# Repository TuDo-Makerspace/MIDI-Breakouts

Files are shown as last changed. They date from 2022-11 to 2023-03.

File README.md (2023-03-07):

# Just another pair of MIDI breakout boards <!-- omit in toc -->

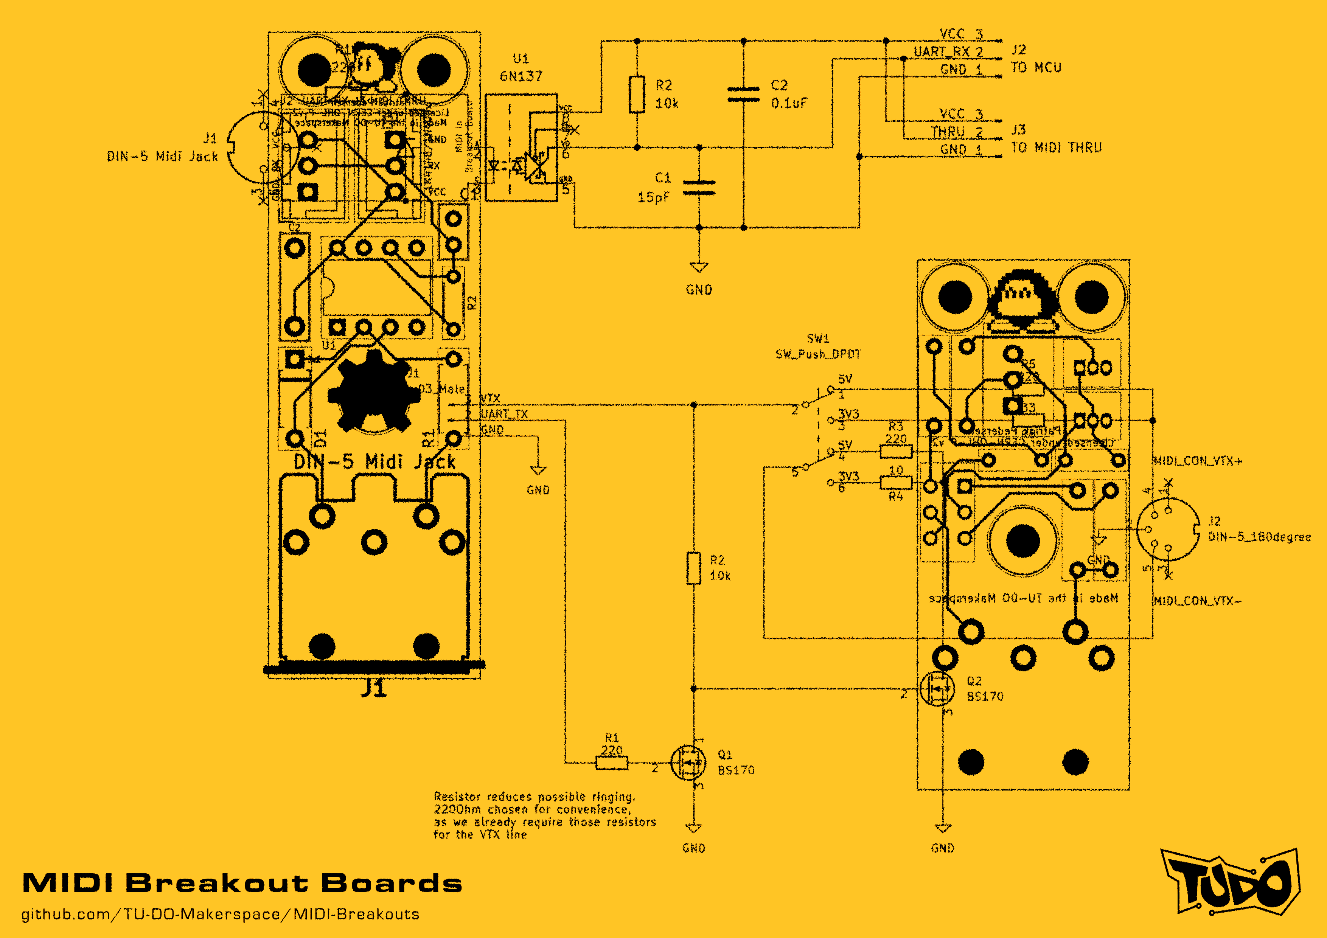
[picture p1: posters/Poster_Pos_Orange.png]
poster


## Table of Contents <!-- omit in toc -->

- [Overview & Background](#overview--background)
- [Noteworthy Features](#noteworthy-features)
- [Schematics](#schematics)
	- [MIDI IN](#midi-in)
	- [MIDI OUT](#midi-out)
- [Ordering](#ordering)
- [Parts & Assembly](#parts--assembly)
- [Pictures](#pictures)
- [License](#license)

## Overview & Background

This repository contains the KiCad files for a pair of MIDI breakout boards. There isn't anything particularly special about them, besides perhaps the fact that the MIDI OUT has a switch to select between 3.3V and 5V operation, as well as two BS170 MOSFETs to sink the current, rather than using buffer chips. Oh, and we use JST-XH connectors, because I hate those loose "DuPont" headers that allow you to plug things in the wrong way around! >:(

Further, one may also question the odd choice of some components, such as the 100nF film capacitor for voltage decoupling, instead of a 100nF ceramic capacitor.
This really leads us to why these boards have even been made in first place. They were really just intended as test boards to try out some [template MIDI schematics](https://github.com/TU-DO-Makerspace/KiCAD-MIDI-Templates) I designed for future projects that require MIDI support. The components were chosen according to the stuff we had lying around in our lab, hence the quirky choice of components and varying resistor footprints.

I'm still dumping this on GitHub, as we still have a few of these boards lying around and the repo serves as good documentation, but perhaps someone out there might also find them useful. After all, if you don't feel like using pricey film caps, you can always just pop in a ceramic one instead! The footprint is not that different!

## Noteworthy Features

MIDI IN:

 - Utilizes the faster 6N137 Optocoupler opposed to the more common 6N138
 - Uses a 15pF decoupling capacitor on the optocoupler's output for better noise immunity
 - Provides two parallel JST-XH connectors:
   - One to connect to the receiving device (eg. a MCU)
   - One to directly connect to a MIDI OUT board which gives you a MIDI THRU output

MIDI OUT:

 - Utilizes two BS170 MOSFETs to sink the current, rather than using buffer chips
 - Has a switch to select between 3.3V and 5V operation
 - Uses a JST XH connector to connect to the sending device (eg. a MCU, or a MIDI IN board for MIDI THRU)

Both boards are compliant with the MIDI Specification

## Schematics

### MIDI IN
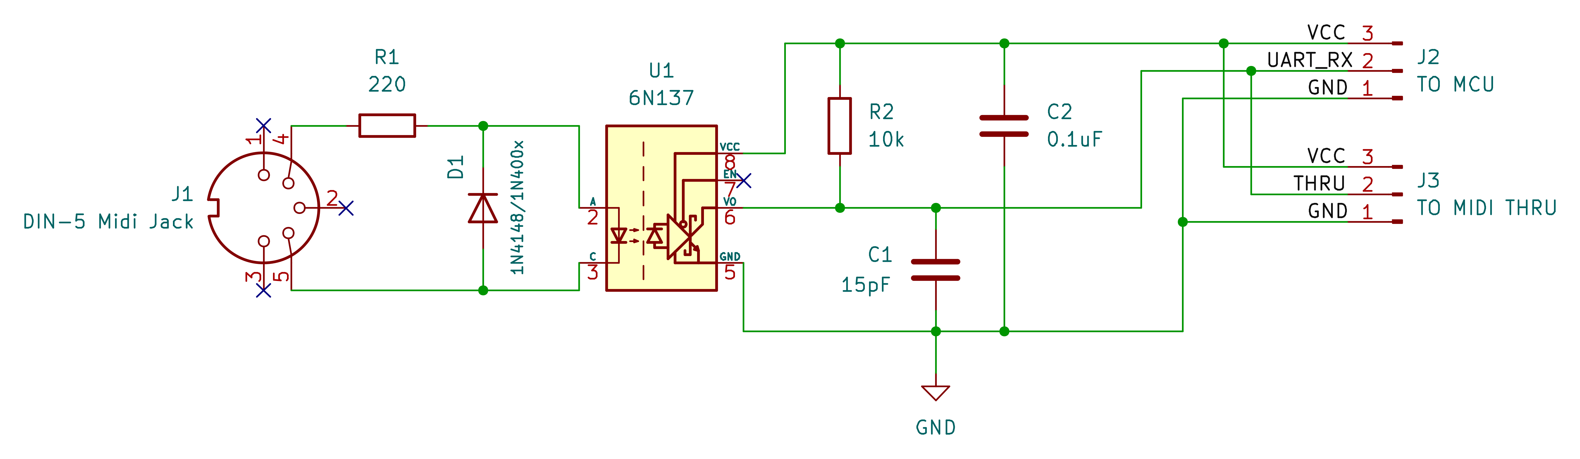
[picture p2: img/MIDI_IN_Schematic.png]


### MIDI OUT
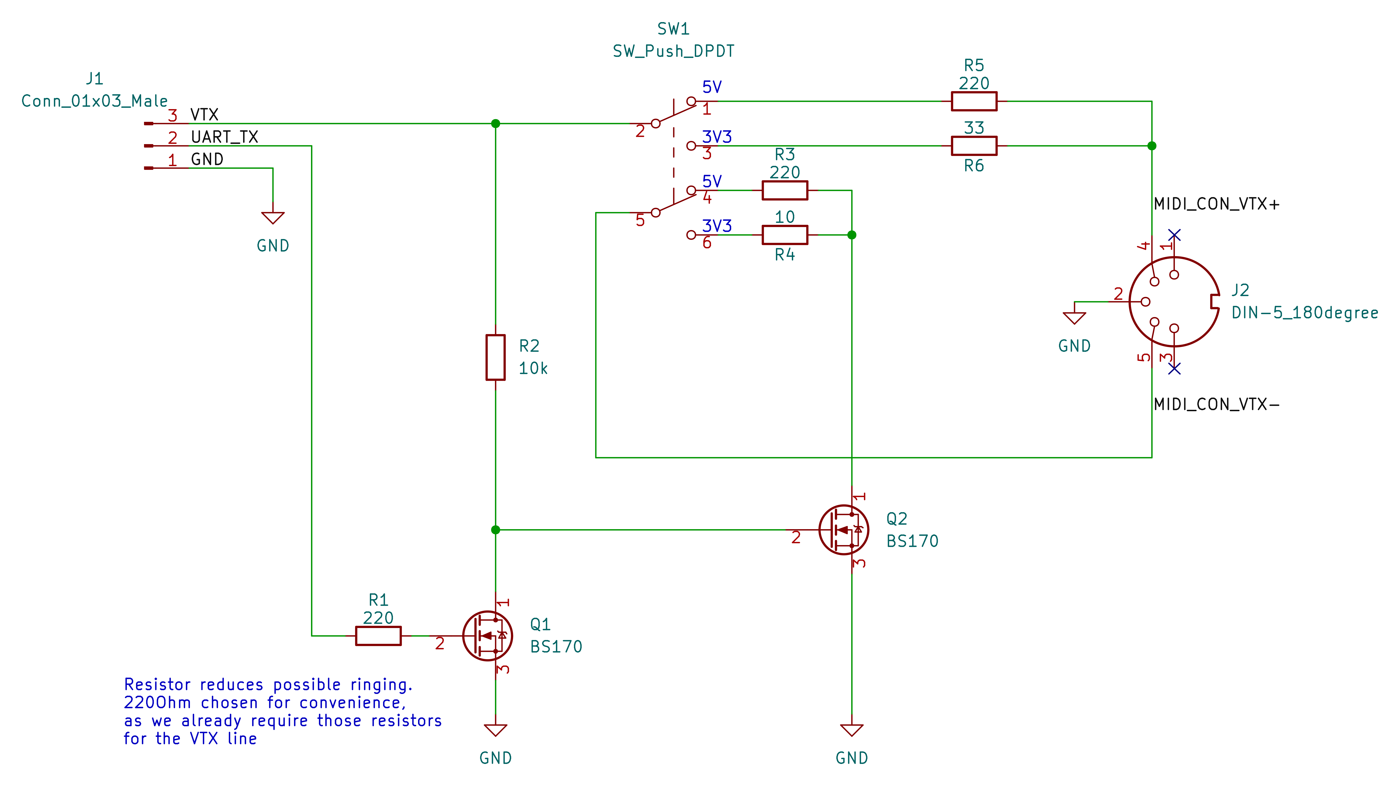
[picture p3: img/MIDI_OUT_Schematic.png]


## Ordering

The directories for the individual boards contain a "Gerbers" directory, which contains the gerber files for the respective board. You can use these to order the boards from your desired PCB manufacturer.

## Parts & Assembly

An interactive BOM for both boards can be found [here](https://tu-do-makerspace.github.io/MIDI-Breakouts/)

The interactive bom contains a PCB view that allows you to see which components go where, and what value they have.
This is particularly useful to have open while assembling the boards.

## Pictures

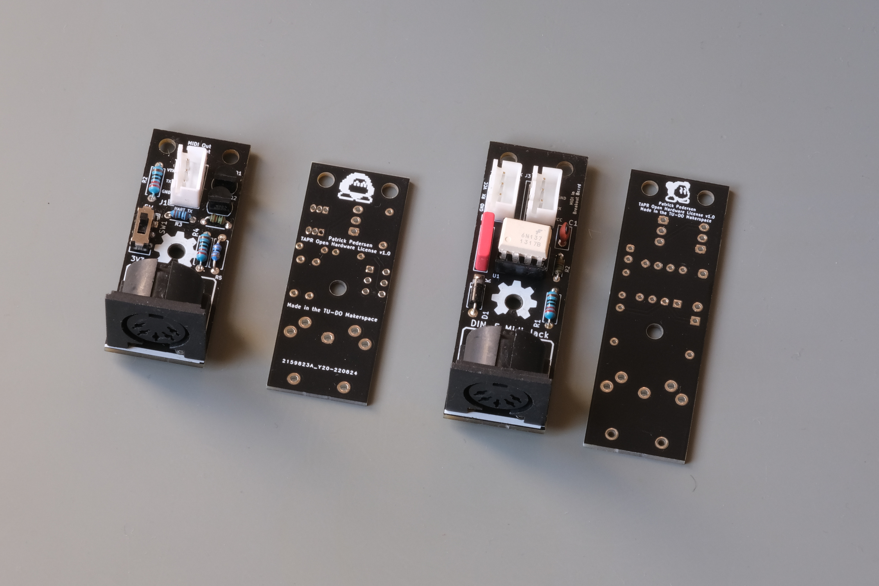
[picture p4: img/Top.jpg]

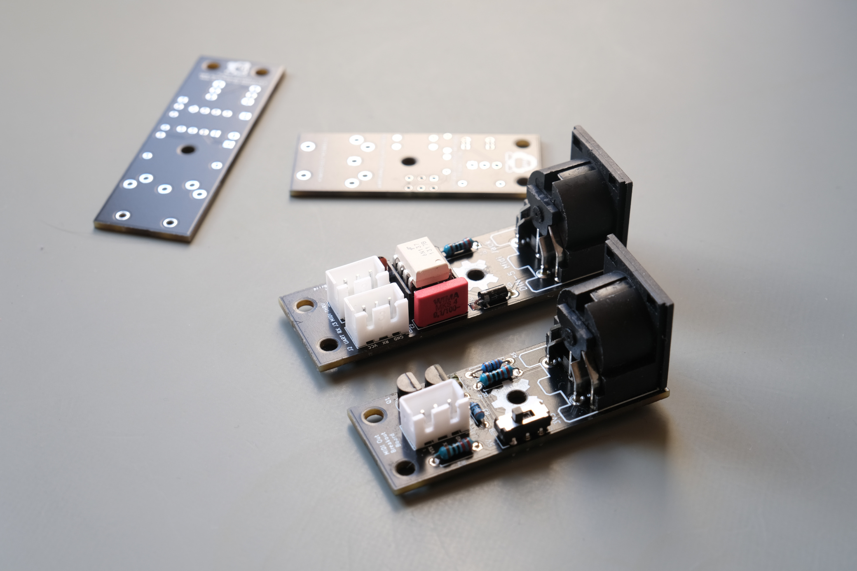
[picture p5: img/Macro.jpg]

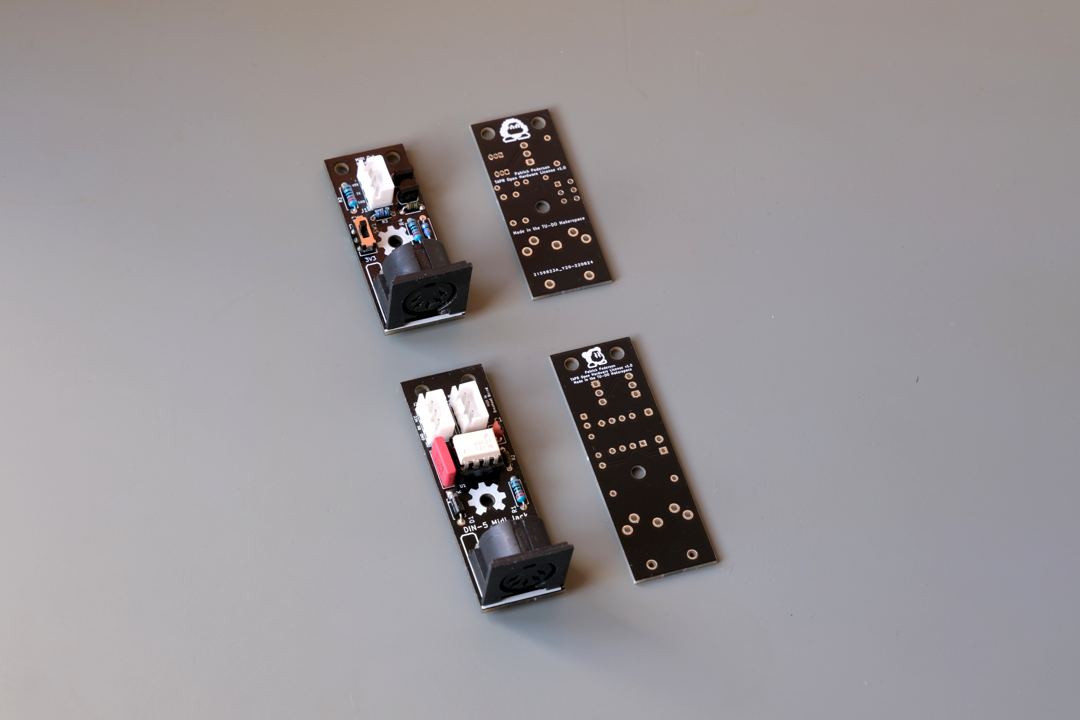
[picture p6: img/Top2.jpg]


## License

The following project is licensed under the [CERN-OHL-P v2 license](https://ohwr.org/cern_ohl_p_v2.pdf)

The boards on the pictures claim `TAPR Open Hardware License v1.0`, however, the KiCAD project has been updated to use the CERN-OHL-P v2 license.

Crediting is always appreciated, even for something as trivial as a pair of breakout boards!

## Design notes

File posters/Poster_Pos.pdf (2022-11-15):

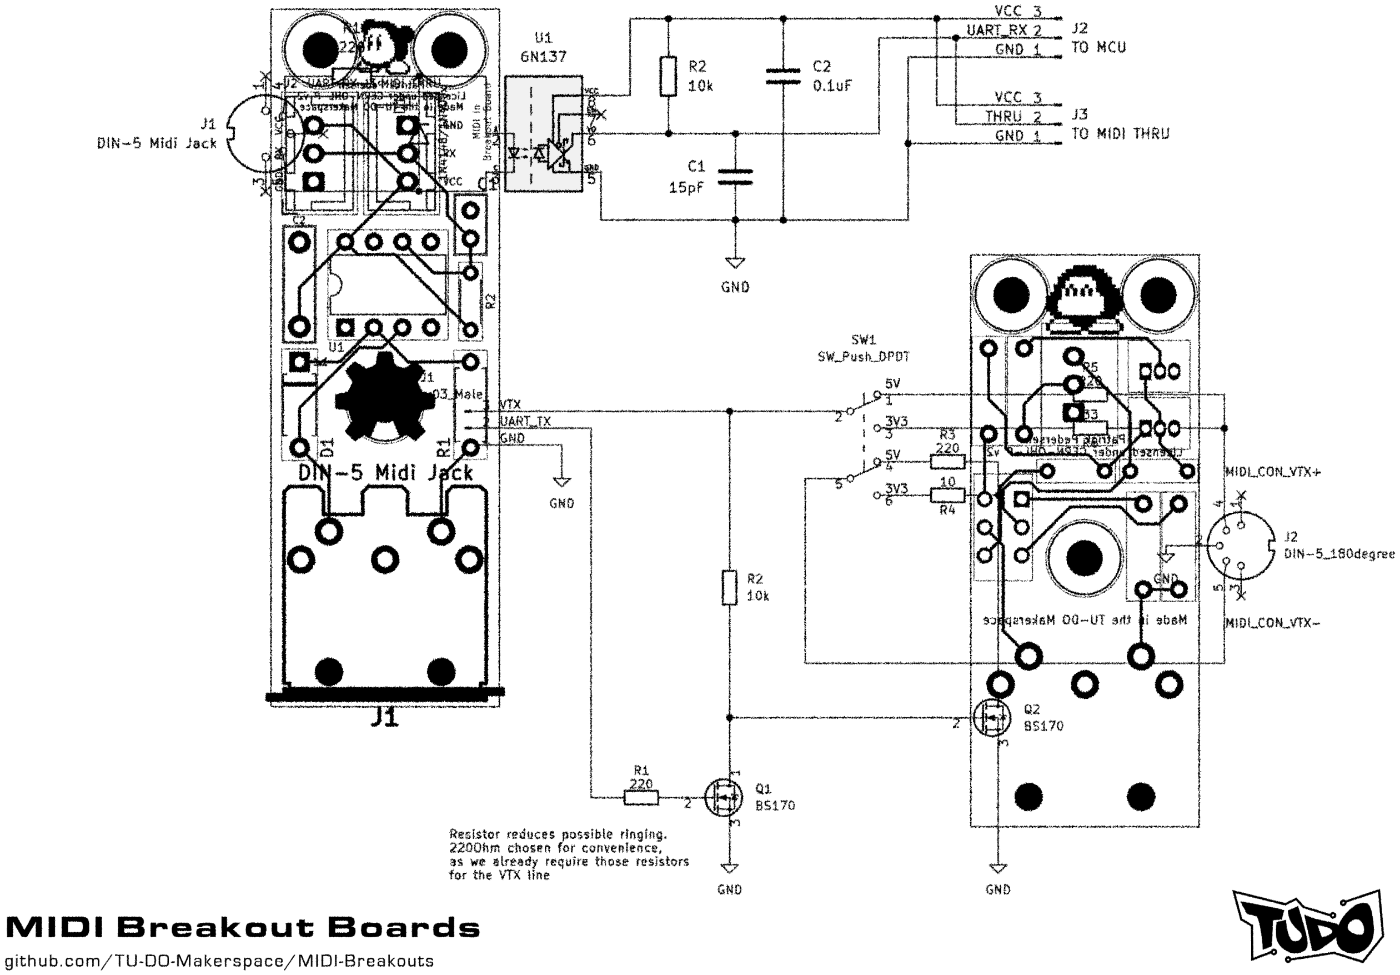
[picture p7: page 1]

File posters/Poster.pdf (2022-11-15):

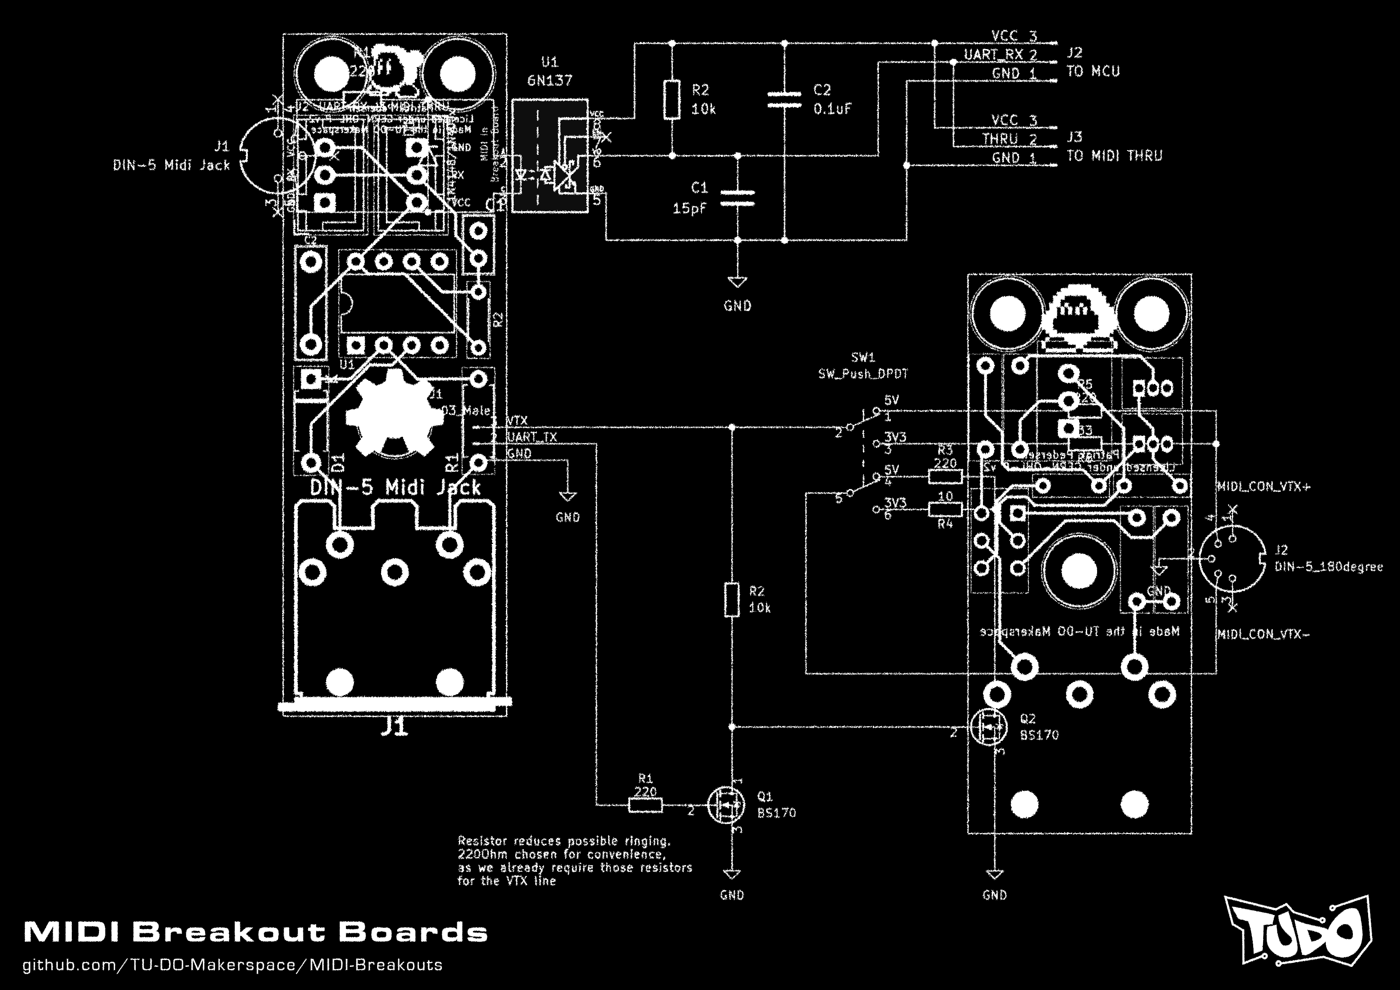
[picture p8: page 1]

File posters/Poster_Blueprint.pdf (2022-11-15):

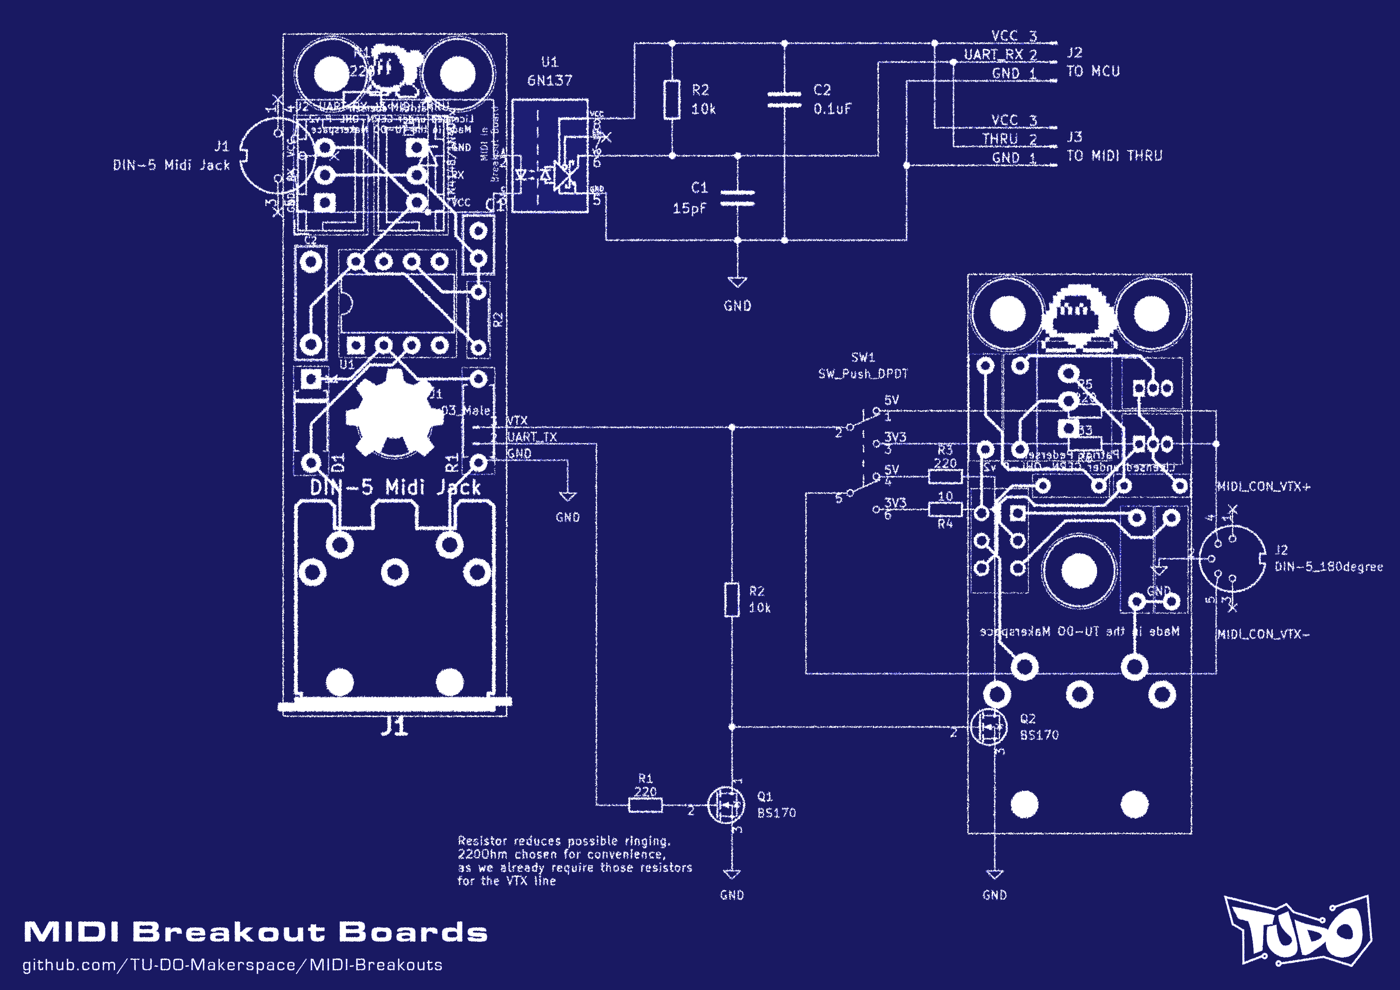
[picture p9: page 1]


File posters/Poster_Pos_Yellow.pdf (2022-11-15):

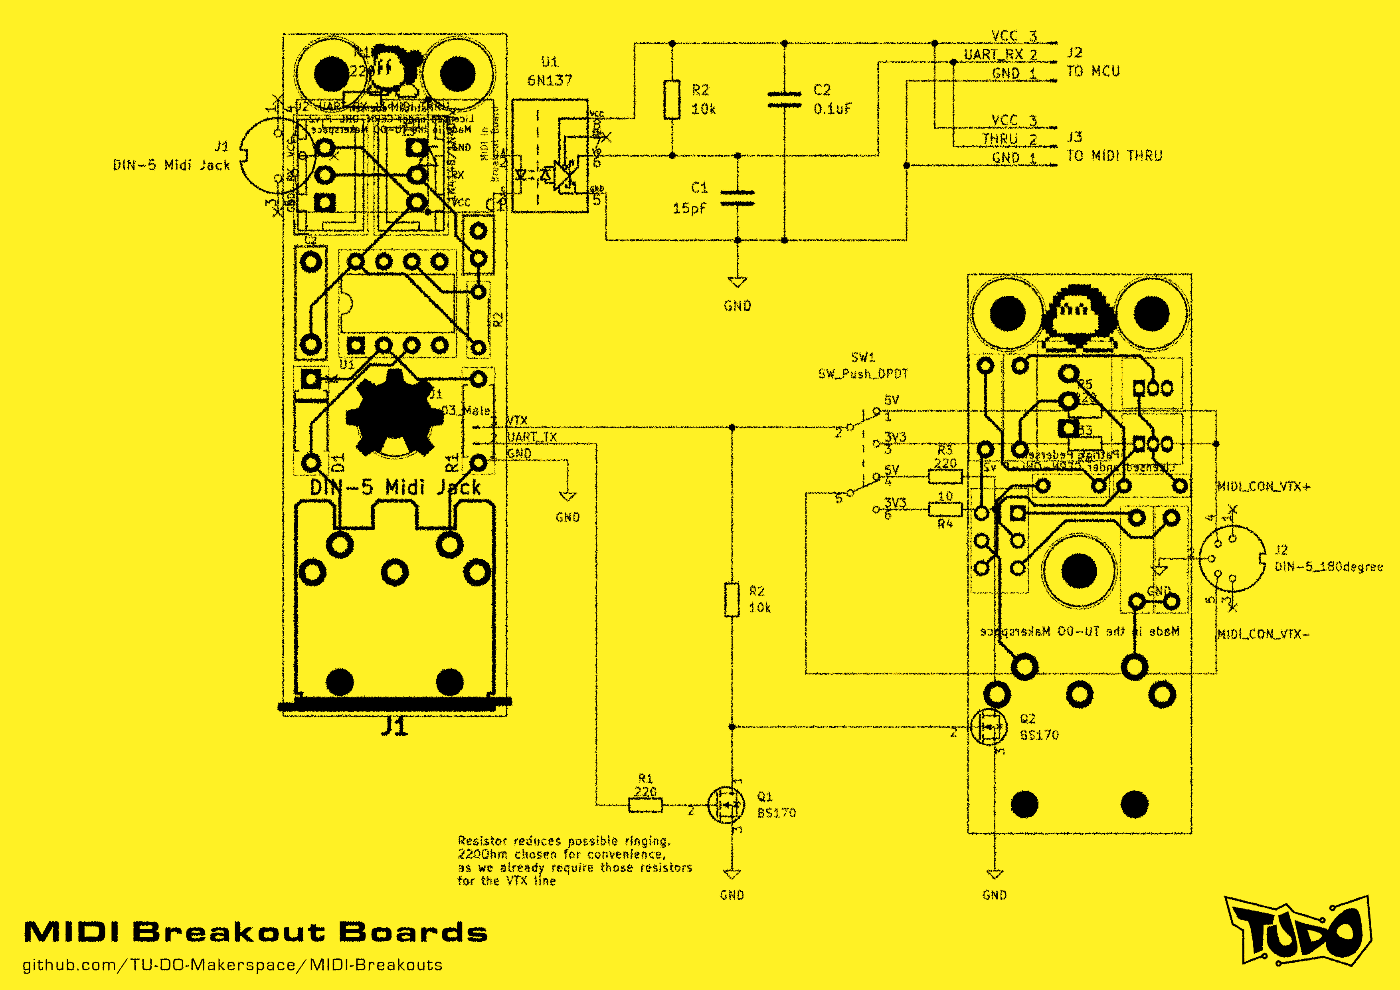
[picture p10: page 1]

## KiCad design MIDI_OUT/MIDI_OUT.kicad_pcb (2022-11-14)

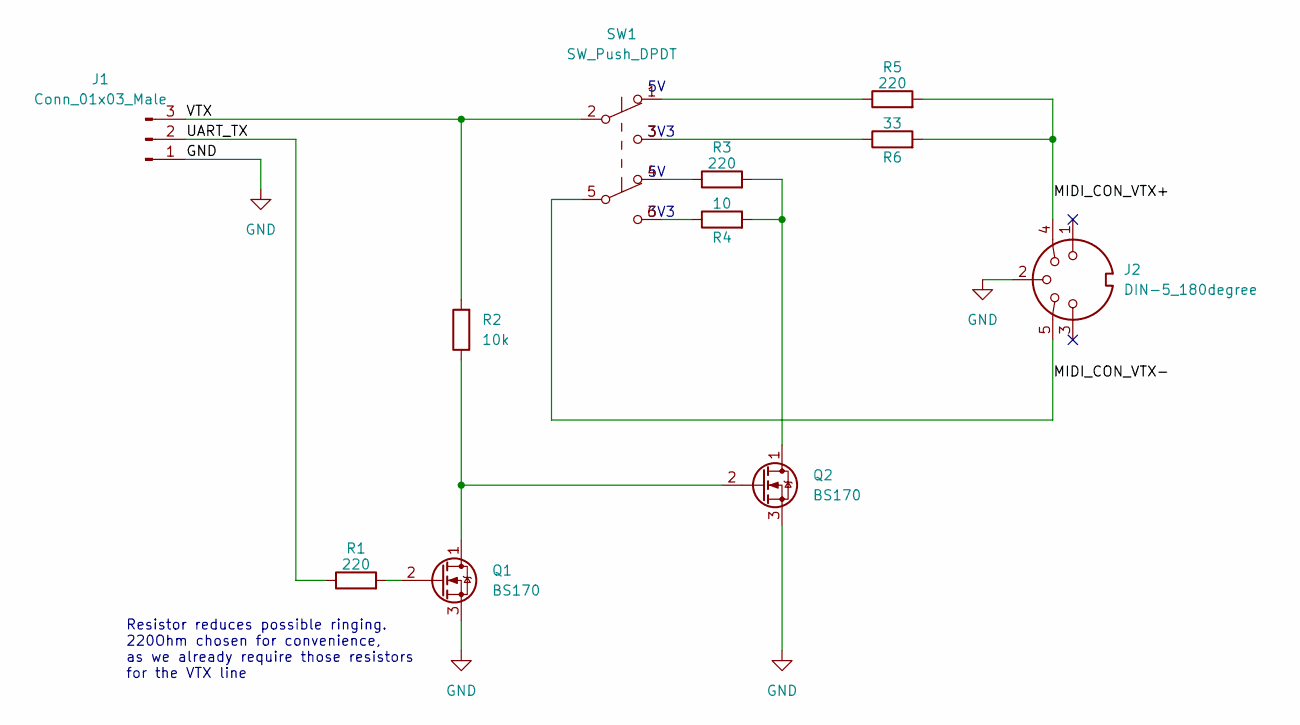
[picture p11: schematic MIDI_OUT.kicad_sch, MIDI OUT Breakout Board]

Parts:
J1: Conn_01x03_Male; JST_XH_B3B-XH-A_1x03_P2.50mm_Vertical
J2: DIN-5_180degree; MIDI_DIN5
Q1, Q2: BS170; TO-92L_Inline
R1, R3, R5: 220; R_Axial_DIN0207_L6.3mm_D2.5mm_P7.62mm_Horizontal
R2: 10k; R_Axial_DIN0204_L3.6mm_D1.6mm_P5.08mm_Horizontal
R4: 10; R_Axial_DIN0204_L3.6mm_D1.6mm_P5.08mm_Horizontal
R6: 33; R_Axial_DIN0207_L6.3mm_D2.5mm_P7.62mm_Horizontal
SW1: SW_Push_DPDT; SW_CuK_JS202011CQN_DPDT_Straight

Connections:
/MIDI_CON_VTX+: J2.4, R5.2, R6.2
/MIDI_CON_VTX-: J2.5, SW1.5 (B)
/UART_TX: J1.2, R1.1
/VTX: J1.3, R2.2, SW1.2 (B)
GND: J1.1, J2.2, Q1.3 (S), Q2.3 (S)
unnamed: Q1.1 (D), Q2.2 (G), R2.1
unnamed: Q1.2 (G), R1.2
unnamed: Q2.1 (D), R3.2, R4.2
unnamed: R3.1, SW1.4 (A)
unnamed: R4.1, SW1.6 (C)
unnamed: R5.1, SW1.1 (A)
unnamed: R6.1, SW1.3 (C)

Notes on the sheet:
3V3
Resistor reduces possible ringing. 220Ohm chosen for convenience, as we already require those resistors for the VTX line

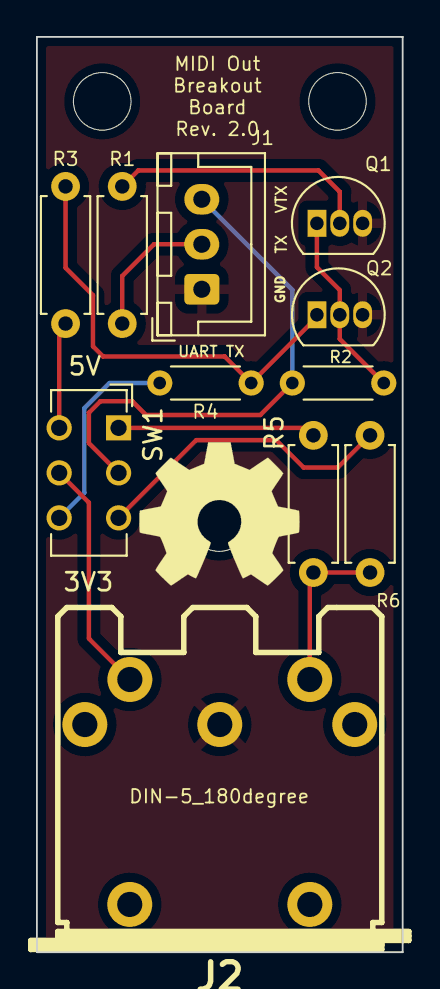
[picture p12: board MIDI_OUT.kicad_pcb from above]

Board: 2 copper layers, 20.3 x 50.9 mm, 11 parts (0 on the bottom side), 12 nets.

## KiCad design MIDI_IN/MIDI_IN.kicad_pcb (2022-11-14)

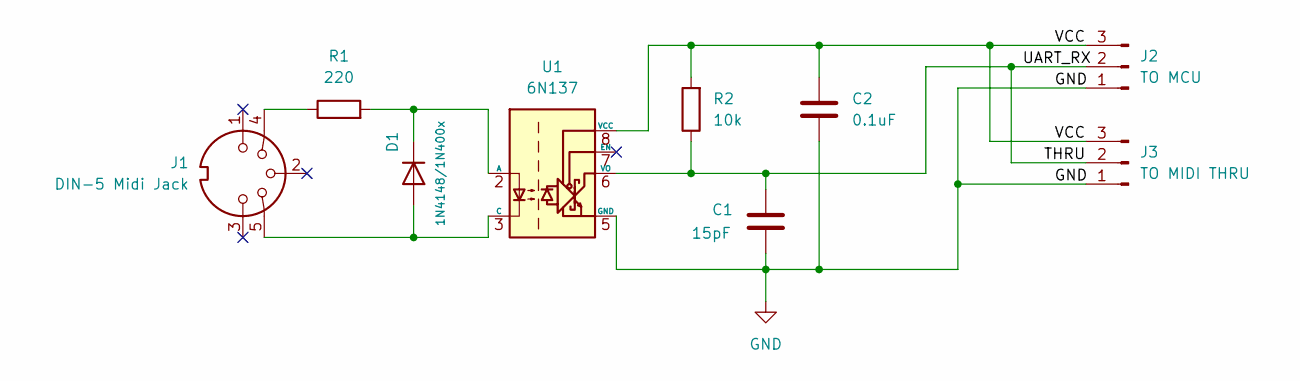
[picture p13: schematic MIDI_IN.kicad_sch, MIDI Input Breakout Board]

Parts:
C1: 15pF; C_Disc_D5.0mm_W2.5mm_P2.50mm
C2: 0.1uF; C_Rect_L10.0mm_W2.5mm_P7.50mm_MKS4
D1: 1N4148/1N400x; D_A-405_P7.62mm_Horizontal
J1: DIN-5 Midi Jack; MIDI_DIN5
J2: TO MCU; JST_XH_B3B-XH-A_1x03_P2.50mm_Vertical
J3: TO MIDI THRU; JST_XH_B3B-XH-A_1x03_P2.50mm_Vertical
R1: 220; R_Axial_DIN0207_L6.3mm_D2.5mm_P7.62mm_Horizontal
R2: 10k; R_Axial_DIN0204_L3.6mm_D1.6mm_P5.08mm_Horizontal
U1: 6N137; DIP-8_W7.62mm

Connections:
/THRU: C1.1, J2.2, J3.2, R2.1, U1.6 (VO)
/VCC: C2.1, J2.3, J3.3, R2.2, U1.8 (VCC)
GND: C1.2, C2.2, J2.1, J3.1, U1.5 (GND)
unnamed: D1.1 (K), R1.2, U1.2 (A)
unnamed: D1.2 (A), J1.5, U1.3 (C)
unnamed: J1.4, R1.1

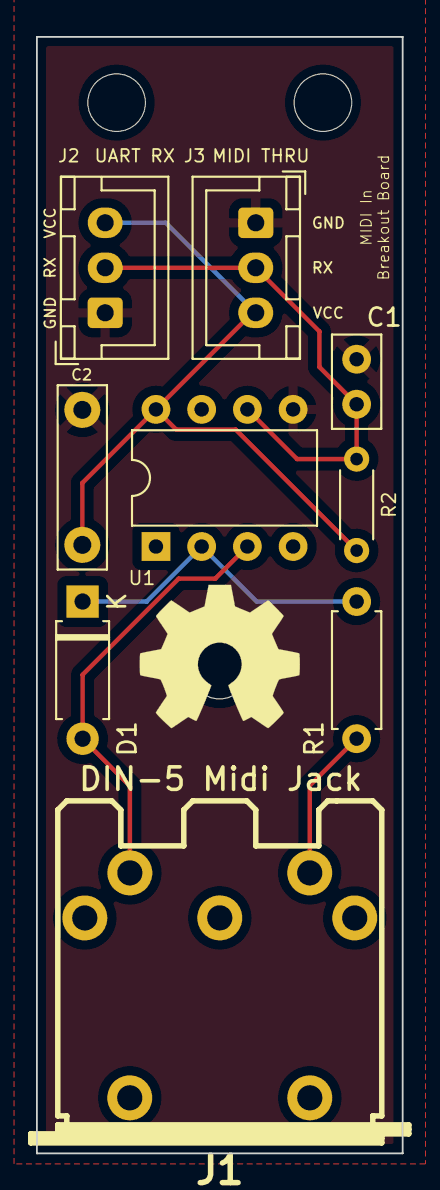
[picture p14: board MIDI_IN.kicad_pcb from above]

Board: 2 copper layers, 20.3 x 62.0 mm, 9 parts (0 on the bottom side), 6 nets.

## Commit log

2022-10-13 Initial commit of v0.0.1
    [MIDI_IN-B_Cu.gbr, MIDI_IN-B_Mask.gbr, MIDI_IN-B_Paste.gbr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]
2022-11-14 Updated license to CERN-OHL-P v2 license
    [MIDI_IN-B_Cu.gbr, MIDI_IN-B_Mask.gbr, MIDI_IN-B_Paste.gbr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]
2022-11-14 README: Added link to template schematics
2022-11-14 README: Added schematics
2022-11-14 MIDI_OUT: Removed gerbers zip
2022-11-24 README: Updated Assembly part

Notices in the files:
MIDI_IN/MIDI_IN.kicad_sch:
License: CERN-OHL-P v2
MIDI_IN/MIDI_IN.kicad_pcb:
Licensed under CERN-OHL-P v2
